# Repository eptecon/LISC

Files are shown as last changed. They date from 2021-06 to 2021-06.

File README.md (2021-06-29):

LISC: Line Image Sensor Controller
======

The Line Image Sensor Controller (LISC) is a universal electronics board that contains readout electronics for various linear image sensors (CCD, CMOS APS, FPA). 
It can be connected to a data acquisition controller (e. g. microcontroller) for further data processing and transmission to a higher-level system. 
The LISC can be used within optical spectrometers and industrial linear cameras.

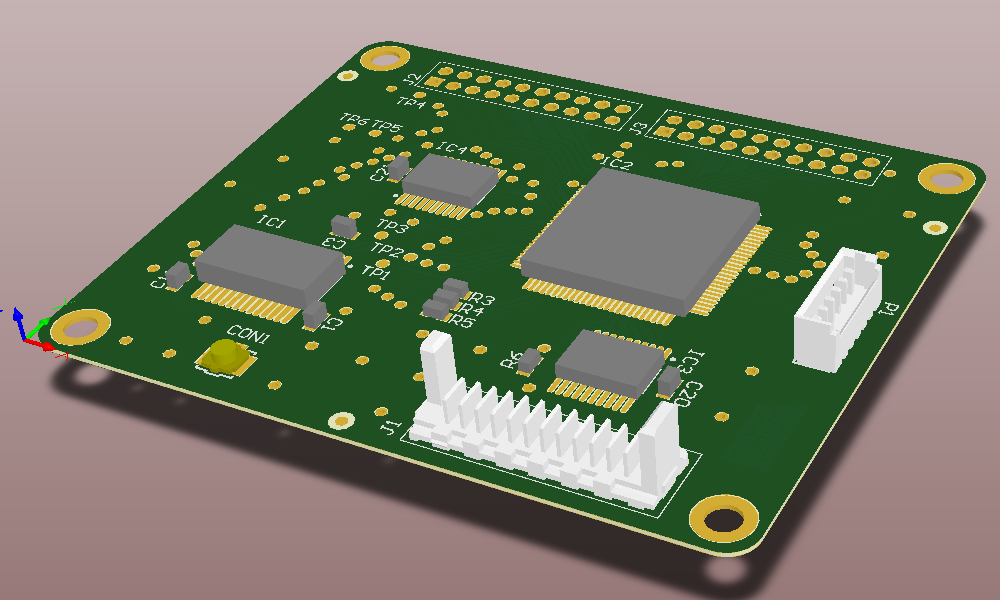
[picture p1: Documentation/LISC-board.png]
 

### Hardware

The Hardware consists of the Electronic Board and the Readout Logic written in VHDL and running on a Xilinx CPLD. See [Documentation](/Documentation/LineImageSensorController.pdf) for details.

### Firmware

The test firmware runs on a STM32F407 microcontroller. It requests the digital video data over DCMI interface using DMA controller and provides it over serial interface
to a user PC.

---

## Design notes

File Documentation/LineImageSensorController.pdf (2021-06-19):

## Line Image Sensor Controller (LISC)

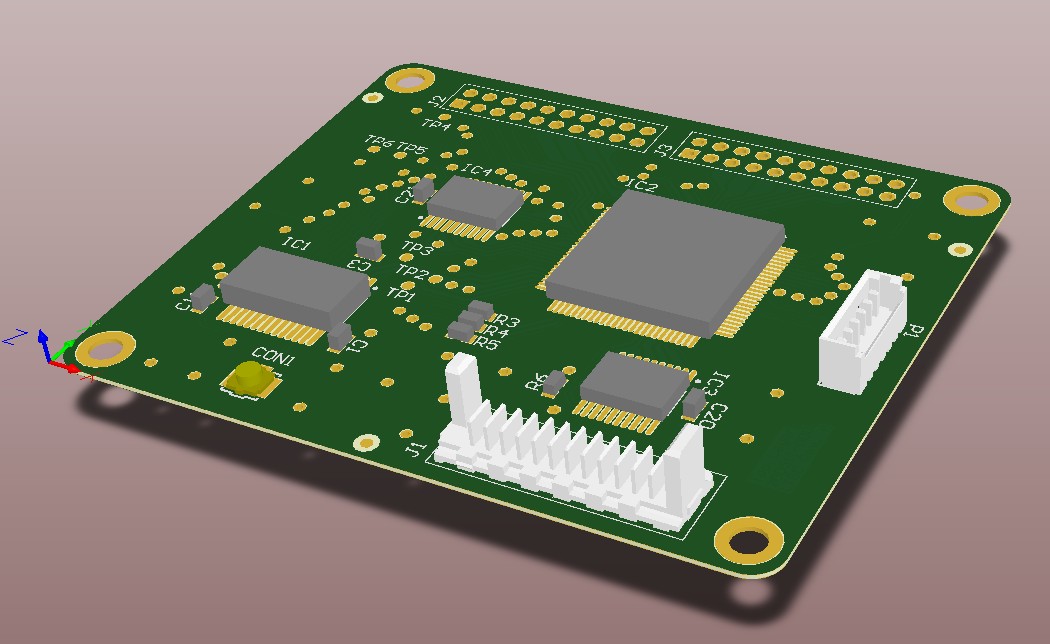
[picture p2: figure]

### 1 Short Description

The Line Image Sensor Controller (LISC) is a universal electronics board that contains readout electronics for various linear image sensors (CCD, CMOS APS, FPA). It can be connected to a data acquisition controller (e. g. microcontroller) for further data processing and transmission. The LISC’s main applications are optical spectrometers and industrial linear camera systems.

The LISC contains following parts:
- Analog-Frontend:
- High resolution: 16 Bit AD-Converter
- Dynamic area: >12 Bit (with adjusted gain)
- Correlated Double Sampling/Sample and Hold circuity
- Programmable gain: 1x to 6x
- Programmable offset. ±300mV
- Fast Readout Logic with Parallel Digital Camera Interface
- Max. readout speed: 2000 kPixels/s
- 4 programmable readout speeds: (500, 1000, 1500 und 2000 kPixel/s)
- Programmable integration time (1,05ms to 60s --> depending on applied line image sensor)
- 8-bit parallel synchronous digital camera interface

### 2 Detailed Specification

### 2.1 Line Image Sensor Controller (LISC)

The Line Image Sensor Controller (LISC) consists of two subsystems: an analog front end and a fast readout logic.
The analog front end contains a video signal processor with analog signal preprocessing and a 16-bit AD converter.
The readout logic is implemented on a CPLD and is used to generate clock signals for various line sensors (tested with CCD line sensors from Sony: ILX511, ILX554). Additionally, the logic takes over the configuration and control of the analog signal preprocessing and the AD conversion. The video data is output via 8-bit parallel (pixel by pixel) synchronous digital camera interface.
The interface to the line image sensor consists of a 12-pin male connector for supply and clock control signals as well a U.FL connector for the analog video signal.

The data interface consists of an 8-bit digital camera interface for video data and a serial interface for configuration of the LISC. The system can be controlled directly via 4 additional inputs. (The data interface can be adapted to use the LISC as a stand-alone module. 8 additional GPIOs are reserved for this purpose.)

LISC Specification
AD-Converter | | | 16Bit
Converion rate | | | 500, 1000, 1500, 2000kSps
Video signal input | 0V bis 4V
Input capacity | | | 10pF
Programmable gain | 0dB bis 16dB (1x bis 6x)
Programmable offset | ±300 mV (tbd (counts))
Elctrical distortion/non-linearity | tbd (counts)
Temperature drift | tbd (counts/°C)
Max. readout speed | 2000kPixel/s
Programmable integration time | 1,05ms to 60ms
Power consumption (w/o sensor) | 1,1W

LISC Line Image Sensor Interface
Pin number | Pin name | I/O | Function
Analog Video Input
CON1-1 | AI1 | IN | Analog video signal
CON1-2 | GND | PWR | analog ground
Line Image Sensor Control Interface
J1-1 | GND | PWR | reserved
J1-2 | SCL | OUT | reserved for I2C
J1-3 | SDA | IN/OUT | reserved for I2C
J1-4 | 3V3 | PWR | reserved
J1-5 | 5V | PWR | supply line sensor
J1-6 | GND | PWR | supply line sensor
J1-7 | RESET1 | OUT | ROG/START – readout start
J1-8 | SENCLK1 | OUT | CLK – readout clock
J1-9 | ADCTRIG | IN | reserved
J1-10 | SENCLK3 | OUT | reserved
J1-11 | RESET2 | OUT | reserved
J1-12 | SENCLK2 | OUT | reserved

LISC Data and
Configuration Interface
Pin number | Pin name | I/O | Function
Serial Config Interface
J2-2 | SCLK | IN | serial clock
J2-4 | MOSI | IN/OUT | serial data
J2-6 | MISO | IN/OUT | serial data
J2-8 | CS | IN | chip select
Parallel Digital Camera Interface
J2-13 | PIXCLK | OUT | pixel clock
J2-15 | VSYNC | OUT | vertical synchronisation
J2-17 | HSYNC | OUT | horizontal synchronisation
J3-4 | DA[0] | OUT | data bit 0
J3-6 | DA[1] | OUT | data bit 1
J3-8 | DA[2] | OUT | data bit 2
J3-10 | DA[3] | OUT | data bit 3
J3-12 | DA[4] | OUT | data bit 4
J3-14 | DA[5] | OUT | data bit 5
J3-16 | DA[6] | OUT | data bit 6
J3-18 | DA[7] | OUT | data bit 7

### 4 Control-I/Os

Pin number | Pin name | I/O | Function
J2-12 | RESET | IN | digital camera reset
J2-14 | START | IN | exteral trigger/start readout
J2-16 | EXTCLK | IN | digital camera main clock
J2-18 | READY | OUT | readout ready
J2-20 | RST | IN | system reset
8x DATA I/Os reserved for alternative interface
Pin number | Pin name | I/O | Function
J3-3 | DB[0] | IN/OUT | reserved
J3-5 | DB[1] | IN/OUT | reserved
J3-7 | DB[2] | IN/OUT | reserved
J3-9 | DB[3] | IN/OUT | reserved
J3-11 | DB[4] | IN/OUT | reserved
J3-13 | DB[5] | IN/OUT | reserved
J3-15 | DB[6] | IN/OUT | reserved
J3-17 | DB[7] | IN/OUT | reserved

### 2.2 Power Supply (PWS)

The Line Image Sensor Controller (LISC) requires stable filtered power supply of 5V from a higher-level system. It has a linear converter on board to create 3.3V for local supply and feeds 5V through to supply line image sensor.

PWS Specification
Voltage input | 5V
Voltage output | 5V
Power consumption max. | >2.5W (tbd)

PWS
Connector
P3
Pin number | Pin name | I/O | Function
J2-1 | 5V | PWR | 5V Supply
J2-2 | GND | PWR | ground

### 2.3 General

The Line Image Sensor Controller (LISC) is implemented on a Printed Circuit Board with the size of 60mmx50mm. The maximum height of populated board is equal or smaller than 12mm.
Storage temperature: -65°C to 150°C
Operating temperature: 0°C to 70°C

### 3 System Description Readout Logic

The readout logic is the main component of the LISC. It is implemented as VHDL code on a CPLD so that the electronic card can be used with different line sensors (CCD, CMOS APS or FPA) by making minor adjustments to the firmware. (the function was tested with ILX511 / ILX554 of CCD line sensors from Sony.)
The readout logic configures and controls the analog signal preprocessing and digitization of sensor data. It also controls the reading of the line sensor and the transmission of the data to a microcontroller.
The readout logic can be controlled directly via three lines. Various parameters (such as readout speed, integration time, etc.) can be set on a register basis via a serial interface. The readout logic consists of several VHDL modules that implement various functions. The individual modules are briefly described below.

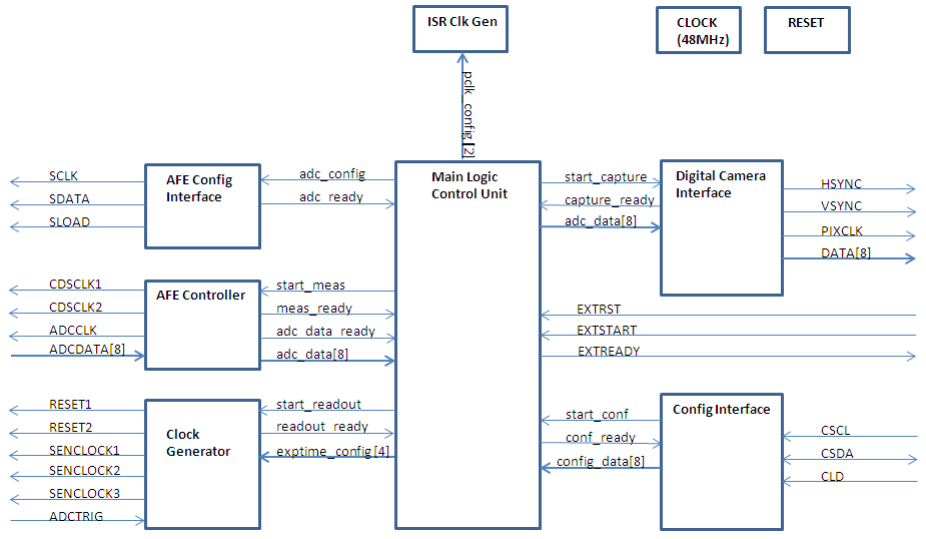
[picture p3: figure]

### 3.1 AFE Config Interface

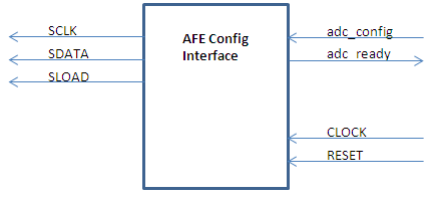
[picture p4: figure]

The AFE-Config Interface (Analog Front-End Config Interface) module configures the AD-converter at every start / reset, or if configuration parameters have been changed via the serial interface of the AD-converter. 8 registers are written to in the AD-converter.

Configuration data of the AD-Converter (AD9826):
- Signal input range (4V or 2V)
- Internal reference (on/off)
- 3-channel-/2- channel -/1- channel -mode (adjustable)
- Analog readout configuration (“correlated double sampling” or “sample and hold“)
- Input clamp bias (4V/3V)
- Sleep mode (on/off)
- Output mode (16Bit/8Bit)
- Multiplexer config (RBG/BGR)
- Channel selection (R/G/B)
- PGA gain (1 bis 6)
- Offset (-300mV bis +300mV)

### 3.2 AFE Controller

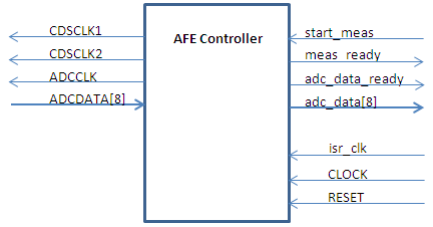
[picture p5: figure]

This module generates signals for sampling (CDS or SHA) and for digitizing the video signal. The signals are then applied to the outputs at the specified times via two control lines. Every time a data item is present at the AD converter output, the adc_data_ready signal is set. The module works synchronously with isr_clk.

### 3.3 Clock Generator

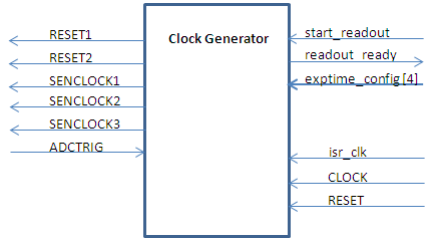
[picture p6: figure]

The clock generator module runs synchronously with isr_clk and generates clock and reset signals for the readout of the line sensor. A different clock generator can be used depending on the line sensor type. The integration time is selected via a 4-bit line.

### 3.4 Main Logic Control Unit

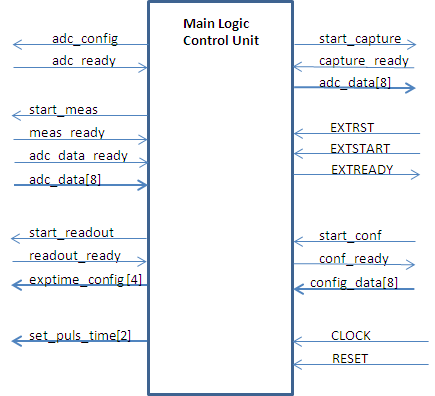
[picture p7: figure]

This module controls all processes (reading, sampling, digitizing, transferring) of the entire readout logic, configures the AD converter, and sets the readout and integration time according to the specified values.
The module is based on a state machine with 3 states:
1. Init: State after switching on / resetting. The system starts the configuration of the AD converter with the existing configuration data. After the successful configuration, the system changes to the second state.
2. Wait for Measurement: The readout process is started in this state. The reading of the line sensor takes place periodically until an external measurement is triggered. The system then changes to the "Measurement" state.
3. Measurement: After triggering, a measurement is carried out. After the configured integration time the digitized data is transmitted to the digital camera output. The system then returns to state 2. If a continuous measurement has been set via the config register, the system remains in that state and continuously sends measurement data to the host. The continuous measurement can only be stopped by an external reset signal.

In the fourth state „CONFIG“ (not implemented yet) the global configuration data (e.g. integration time) are read in and all registers of the readout logic are loaded accordingly.

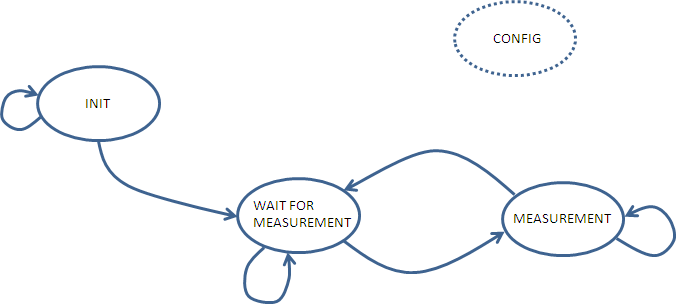
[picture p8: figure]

Higher Level configuration data for Readout Logic von Auslese-Logik:
- Integration time (1,05ms bis 60s)
- Readout speed (0,5MHz bis 2MHz)
- Measurement mode (Einzelmessung/Dauermessung)
- Analog frontend configuration (gain, offset, output mode (8Bit/16Bit))

### 3.5 Digital Camera Interface

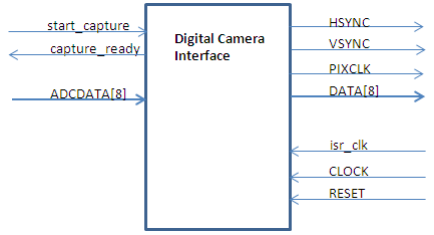
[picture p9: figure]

This module serves as an interface to the host system (e.g. to a microcontroller). It is based on a parallel synchronous digital camera interface with 8-bit data width. For the test system an STM32F407 microcontroller was used. This microcontroller can receive the data via its DCMI interface using Direct Memory Access (DMA) and store or process it further.

### 3.6 Config Interface

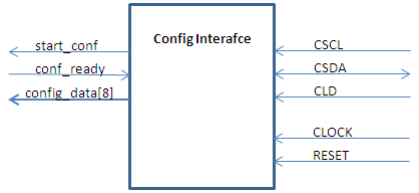
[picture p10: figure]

This module contains a serial interface for higher level configuration of the readout logic. The configuration interface module has not been implemented yet since it requires a more precise specification first.

### 3.7 ISR-Clock Generator

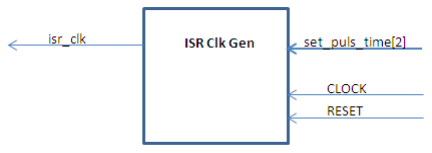
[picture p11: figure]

The ISR clock generator module generates the isr_clk signal from the 48Mhz oscillator, which is used as the main clock for the AFE controller and clock generator as well as for the digital camera interface. The input set_puls_time is used to select the readout speed that was configured on startup.

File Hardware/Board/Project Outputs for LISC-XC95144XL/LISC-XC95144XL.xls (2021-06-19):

Board Stack Report
Stack Up |  |  |  |  | Layer Stack
Layer | Board Layer Stack | Board Layer Stack | Board Layer Stack | Board Layer Stack | Name | Material | Thickness | Constant
1 |  |  |  |  | Top Paste
2 |  |  |  |  | Top Overlay
3 |  |  |  |  | Top Solder | Solder Resist | 0,010mm | 3,5
4 |  |  |  |  | Top Layer | Copper | 0,036mm
5 |  |  |  |  | Dielectric1 | FR-4 | 0,320mm | 4,8
6 |  |  |  |  | Bottom Layer | Copper | 0,036mm
7 |  |  |  |  | Bottom Solder | Solder Resist | 0,010mm | 3,5
8 |  |  |  |  | Bottom Overlay
9 |  |  |  |  | Bottom Paste
 | Height : 0,411mm | Height : 0,411mm | Height : 0,411mm | Height : 0,411mm

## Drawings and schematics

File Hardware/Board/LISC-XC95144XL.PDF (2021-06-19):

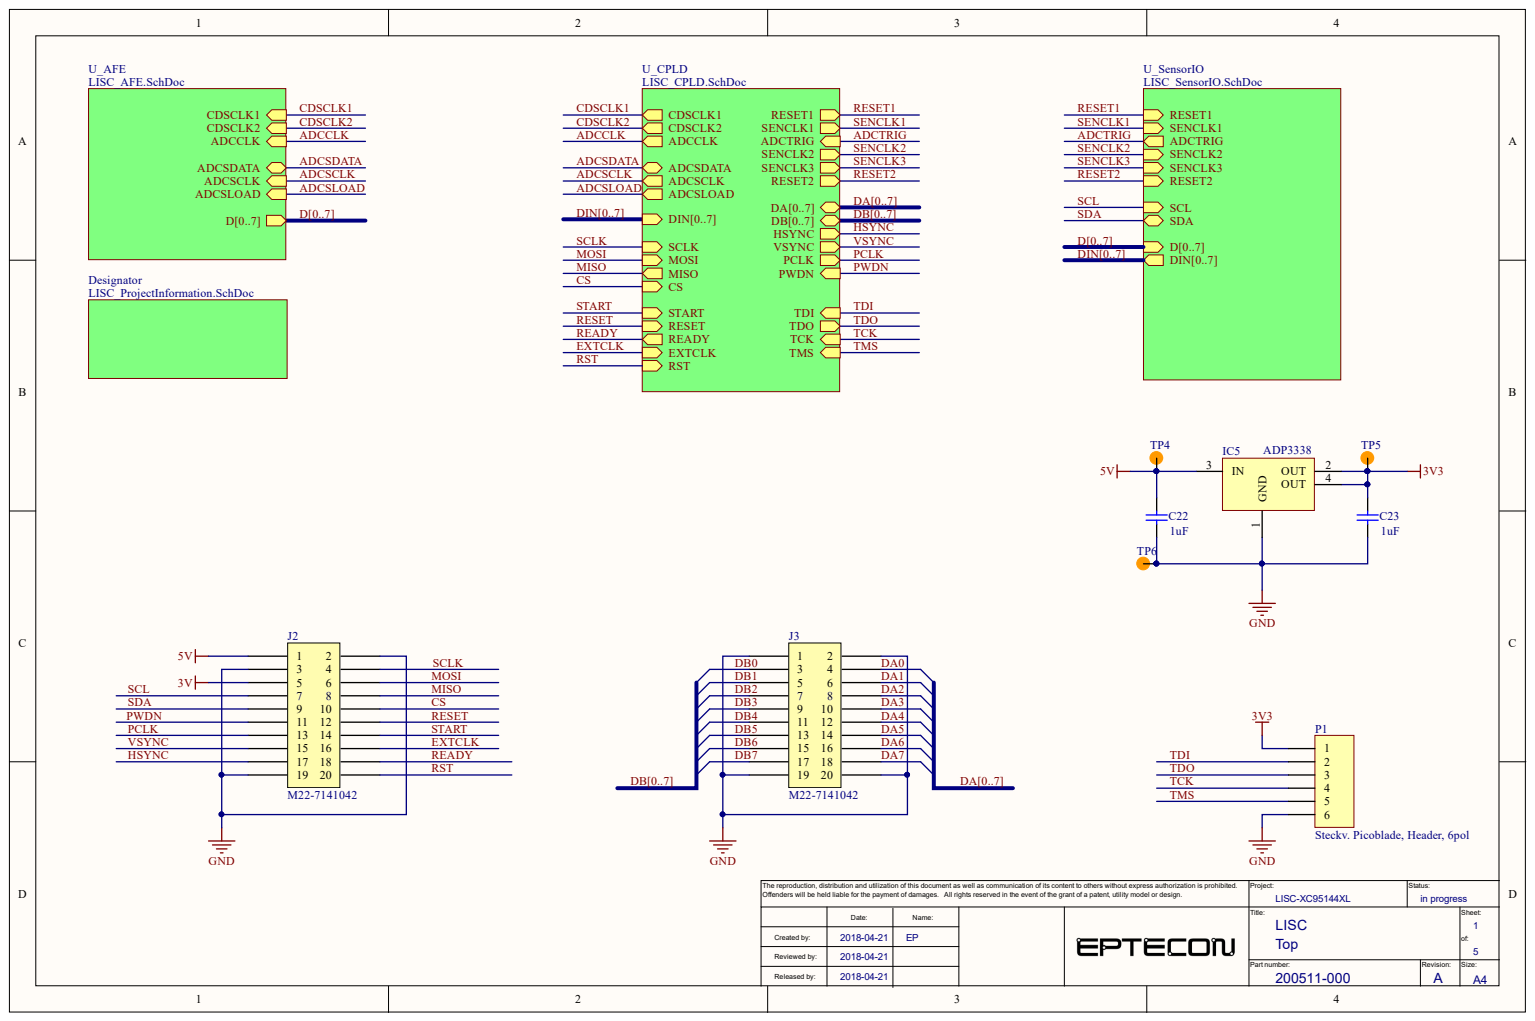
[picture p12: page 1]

The reproduction, distribution and utilization of this document as well as communication of its content to others without express authorization is prohibited. Offenders will be held liable for the payment of damages. All rights reserved in the event of the grant of a patent, utility model or design. | Project: LISC-XC95144XL | Status: in progress

Date: | Name: | Title: LISC Top | Sheet: 1 of: 5

Created by: | 2018-04-21 | EP

Reviewed by: | 2018-04-21

Part number: 200511-000 | Revision: A | Size: A4

Released by: | 2018-04-21

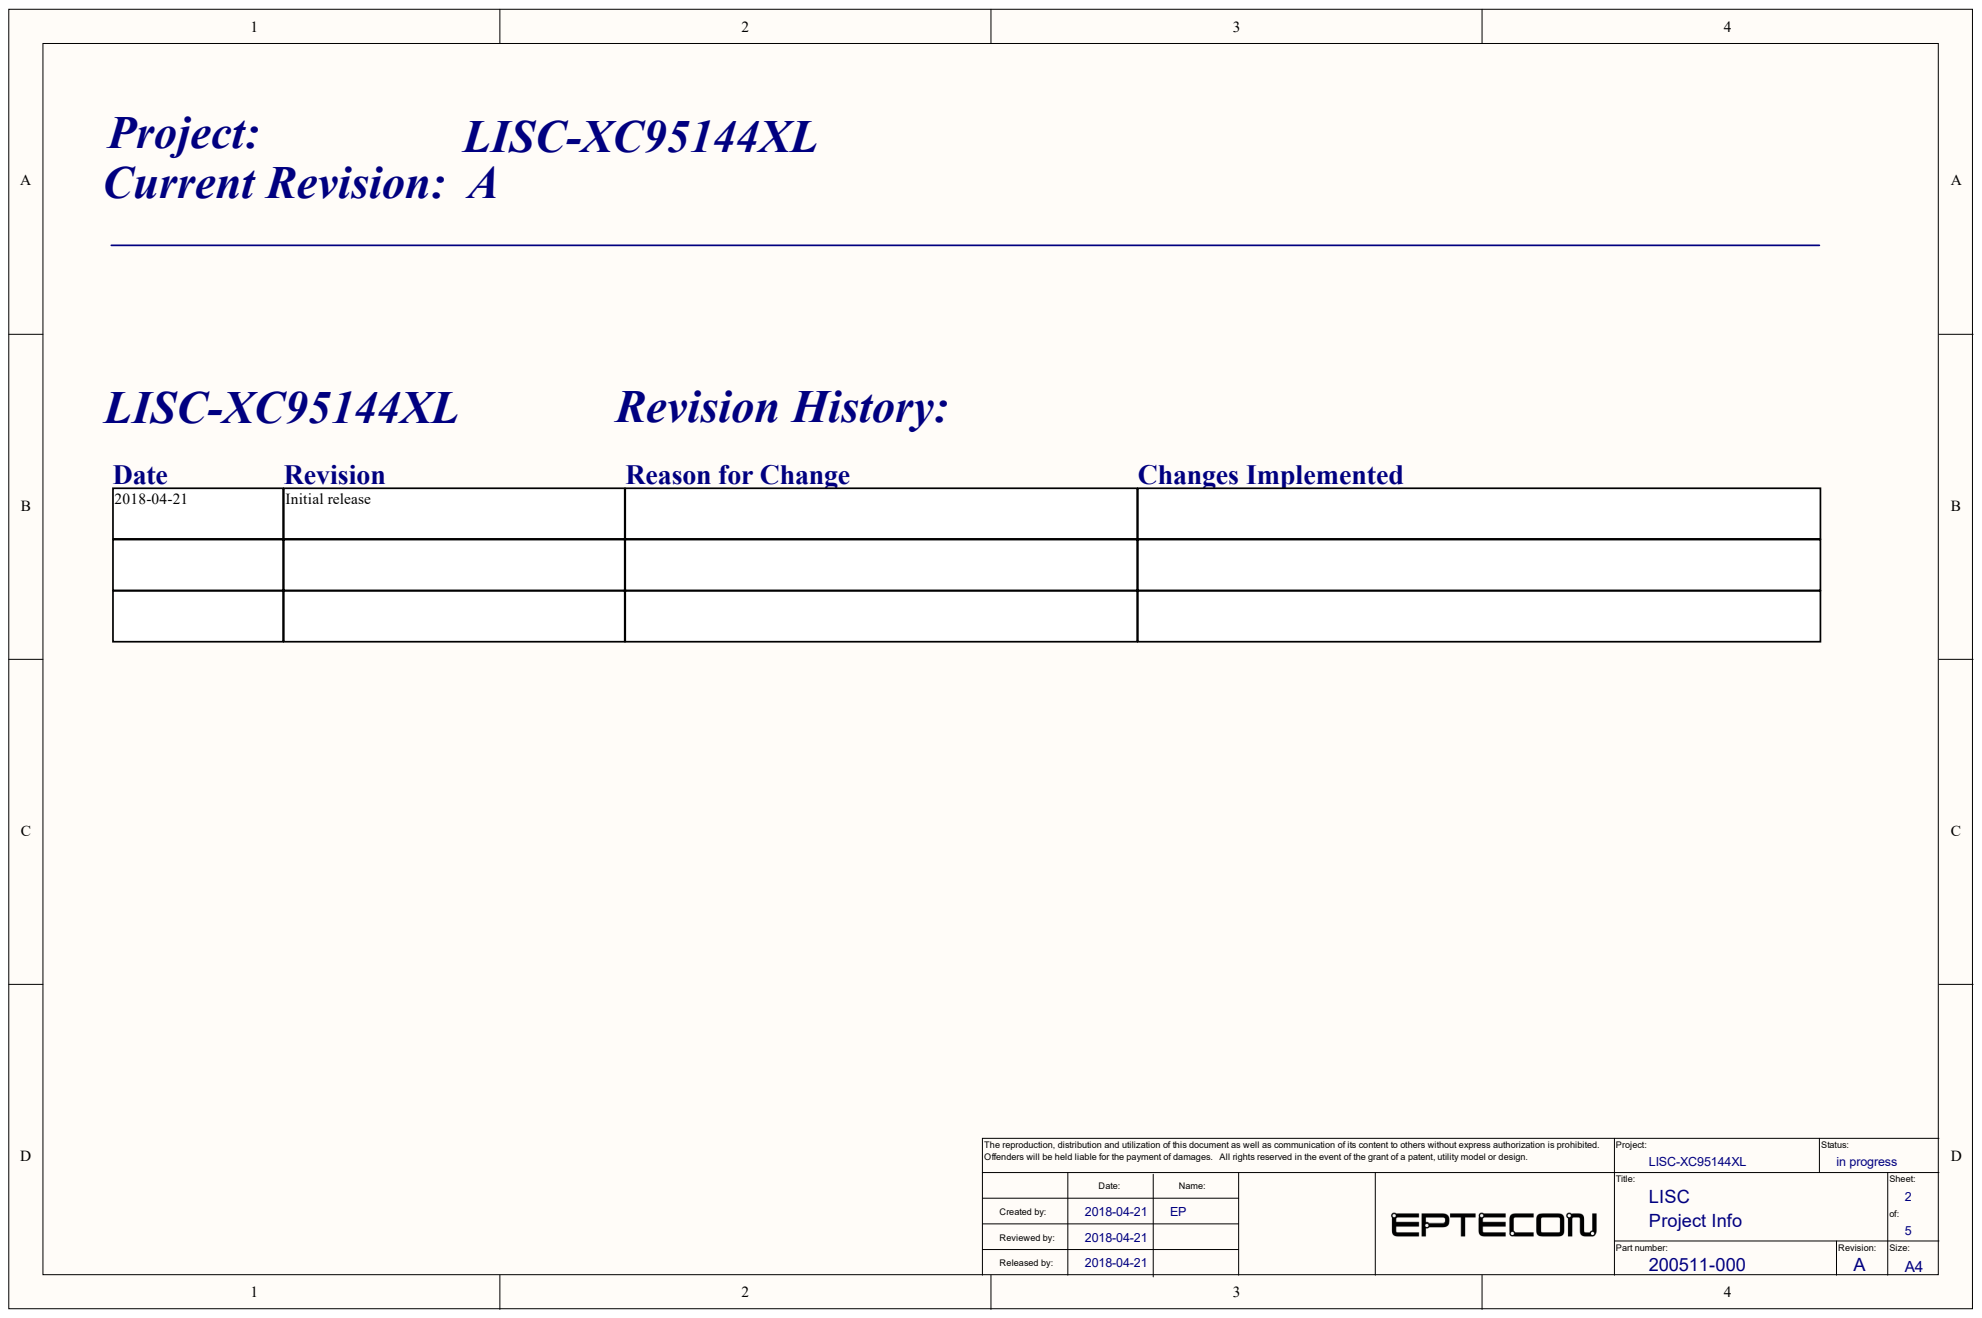
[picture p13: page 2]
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

Date: | Name: | Title: LISC Project Info | Sheet: 2 of: 5

Created by: | 2018-04-21 | EP

Reviewed by: | 2018-04-21

Part number: 200511-000 | Revision: A | Size:

Released by: | 2018-04-21

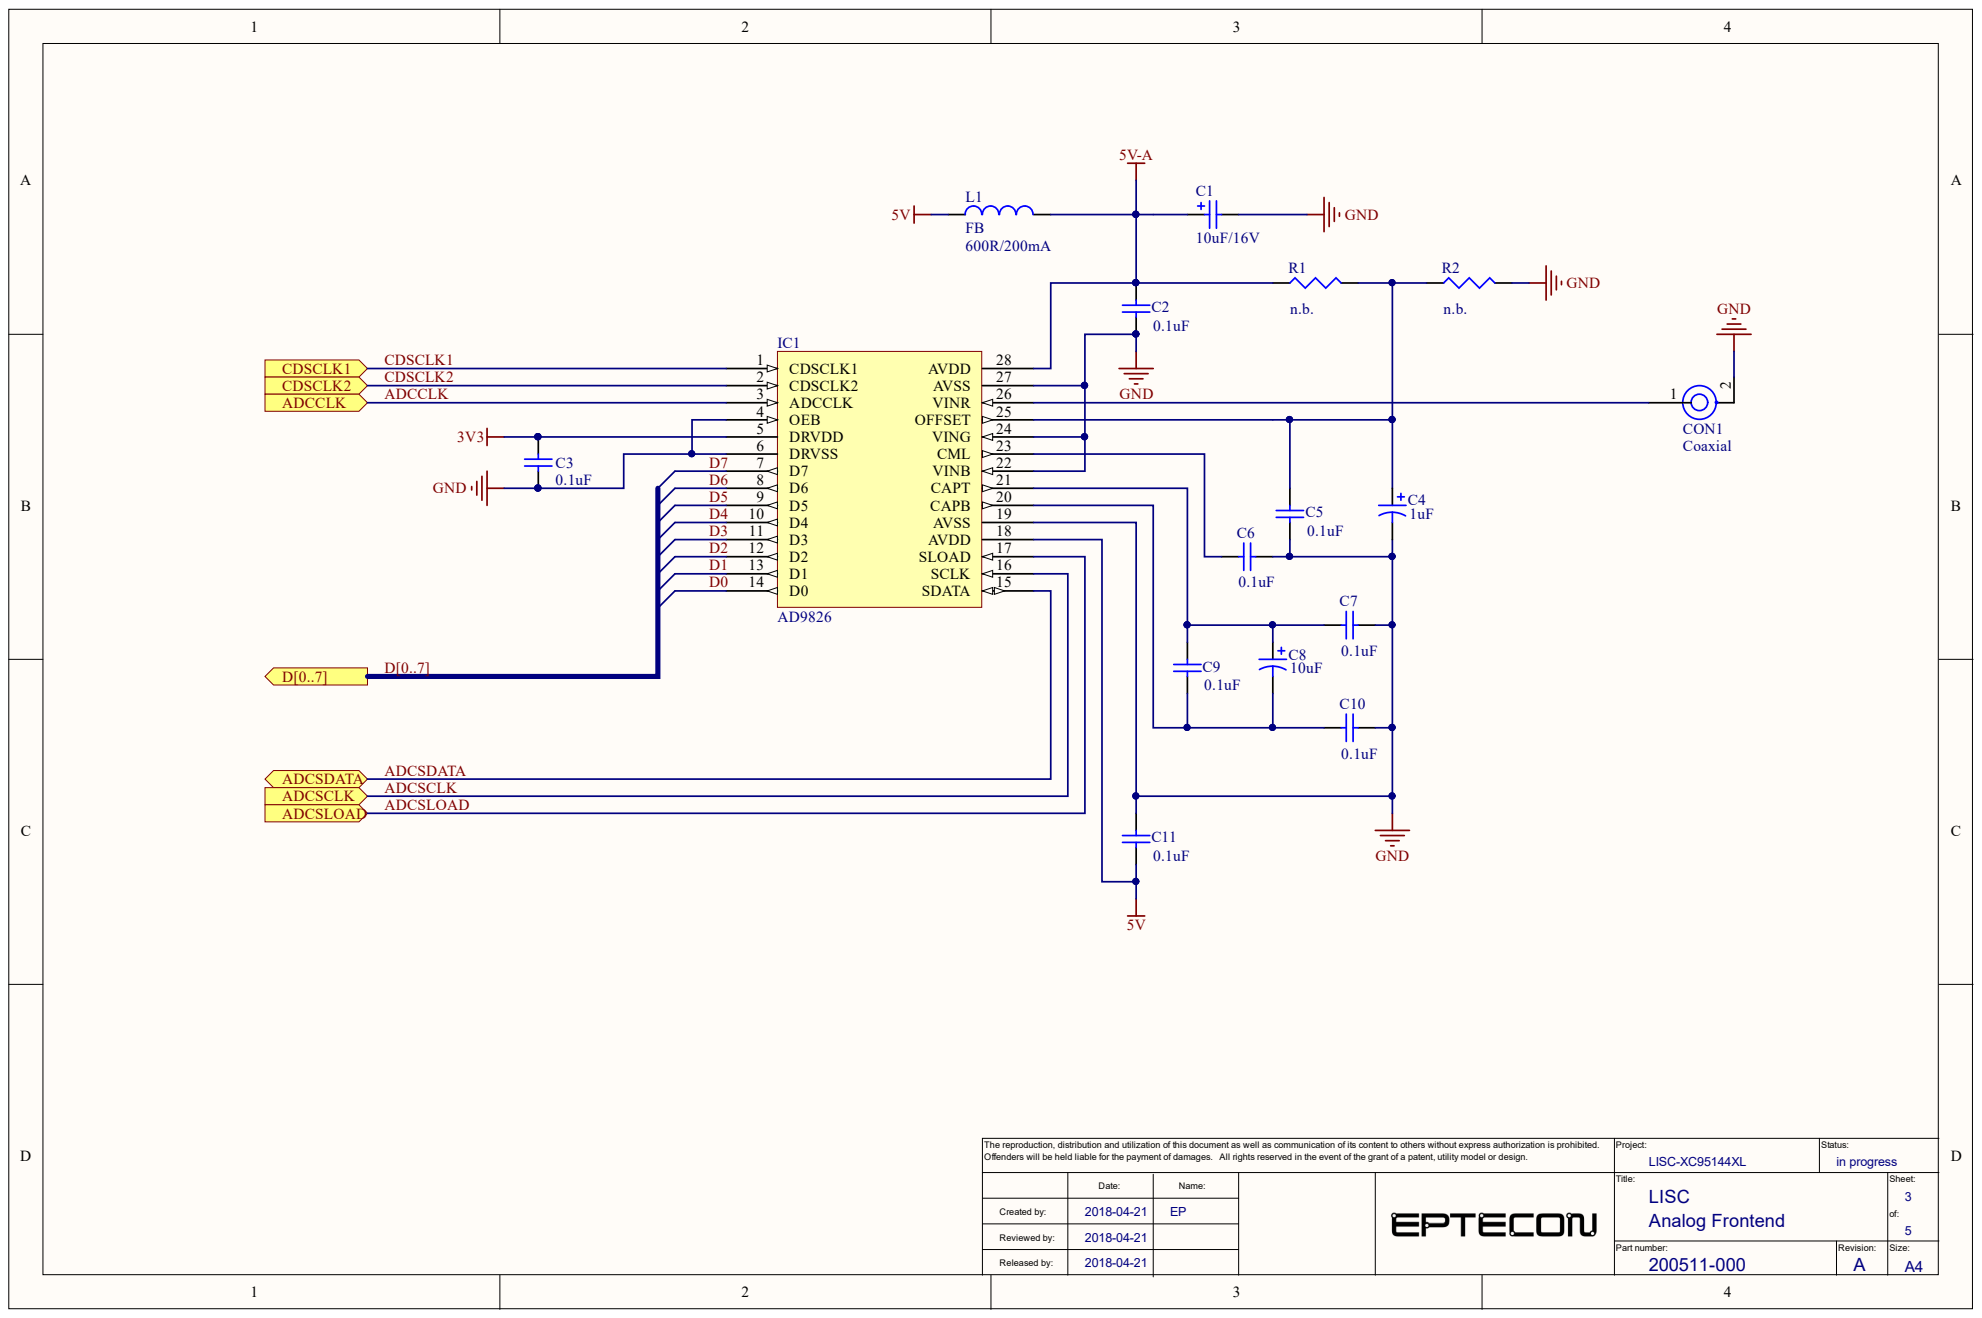
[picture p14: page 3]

5 | | 16 SLOAD 17 AVDD 18 AVSS 19 CAPB 20 CAPT 21 VINB 22 CML 23 VING 24 OFFSET 25 VINR 26 AVSS 27 AVDD 28 5 SCLK

D 1 1 3 | D 1 | | u F
D 0 1 | | 1

D[0..7 ] | | D 0 ATA

The reproduct ion, dist r ibut ion and ut i l izat ion of this document as wel l as com municat ion of i ts content to others w i thout express author izat ion is prohibi ted. O ffenders w i l l be held l iable for the payment of damages. A l l r ights reserved in the event of the grant of a patent , ut i l i ty model or design. | P roject : LISC-XC9 5 1 4 4 X L | S tatus: in p r o g r ess

Date: | Name: | T i t le: LIS C Analog F rontend | Sheet : 35 of :

C reated by: | 2 0 1 8 -0 4 -2 1 | E P

Reviewed by: Released by: | 2 0 1 8 -0 4 -2 1

Part number : 200511-000 | Revision: A | S ize:

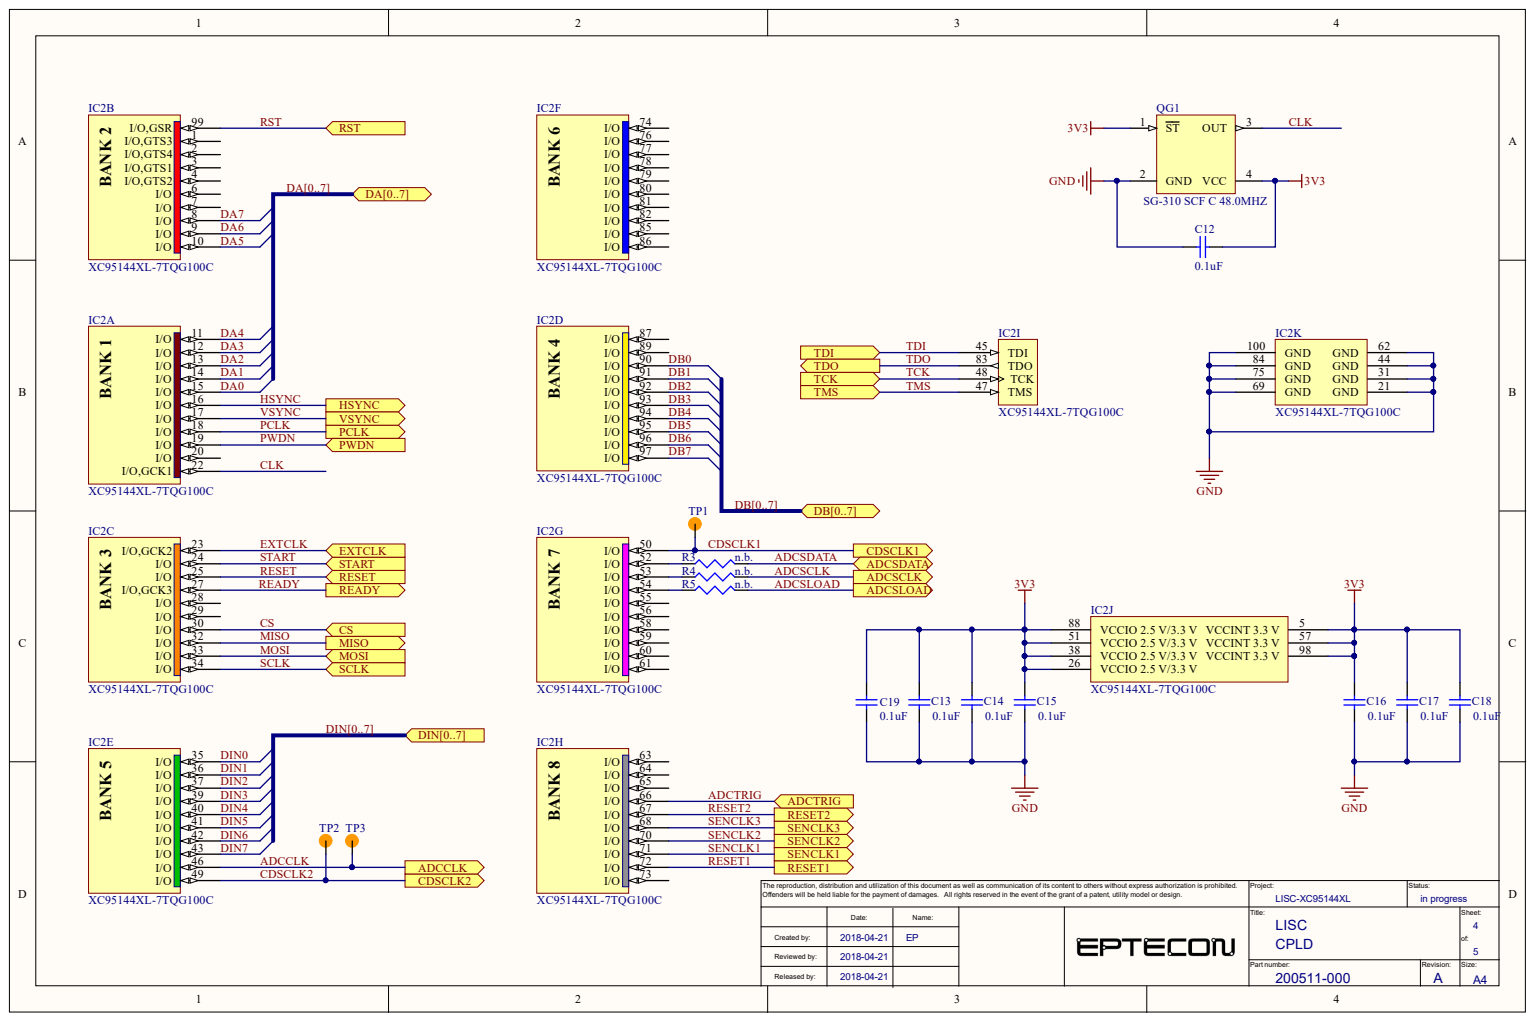
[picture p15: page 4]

8 4 | 4 4
7 5 | 3 1

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

Date: | Name: | T i t le: LIS C CPLD | Sheet : 45 of :

C reated by: | 2 0 1 8 -0 4 -2 1 | E P

Reviewed by: Released by: | 2 0 1 8 -0 4 -2 1

Part number : 200511-000 | Revision: A | S ize:

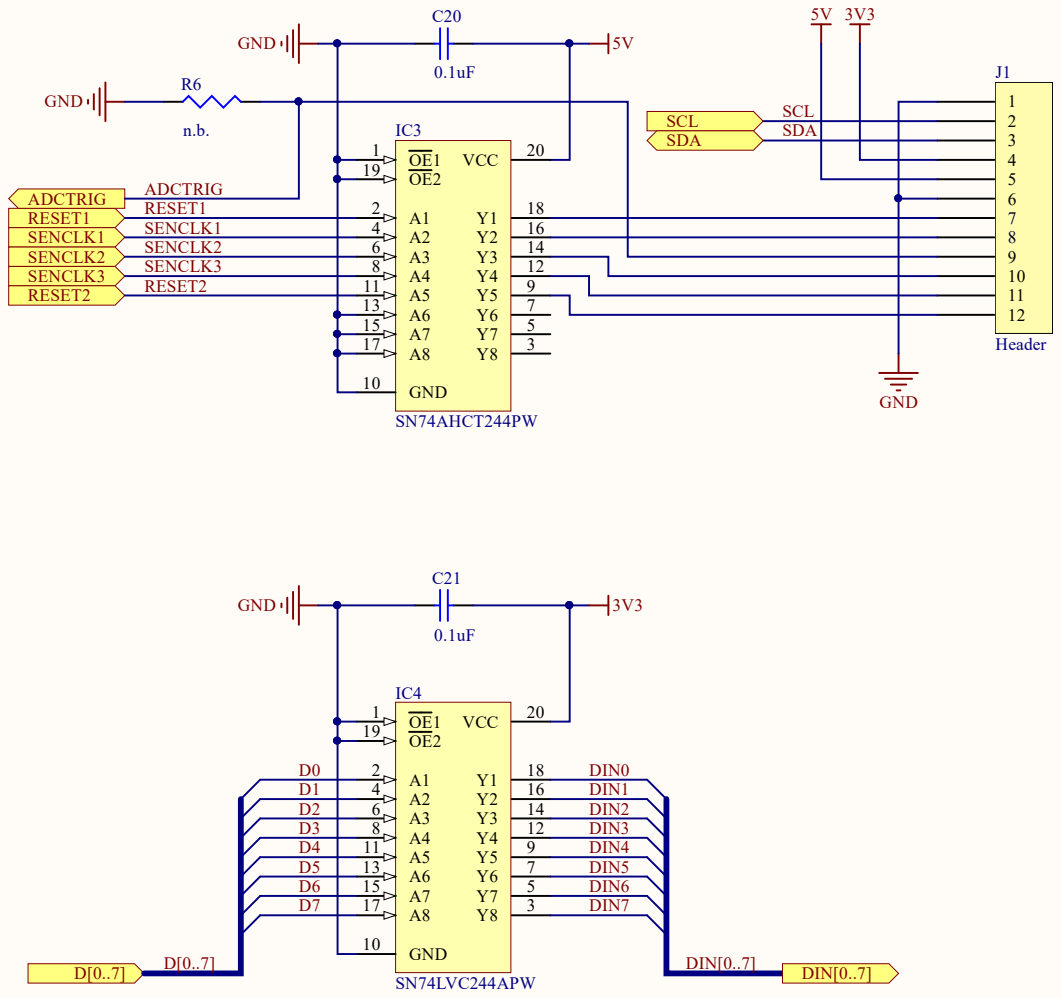
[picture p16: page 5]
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

Date: | Name: | Title: LISC Sensor I/O | Sheet: 5 of: 5

Created by: | 2018-04-21 | EP

Reviewed by: | 2018-04-21

Part number: 200511-000 | Revision: A | Size:

Released by: | 2018-04-21

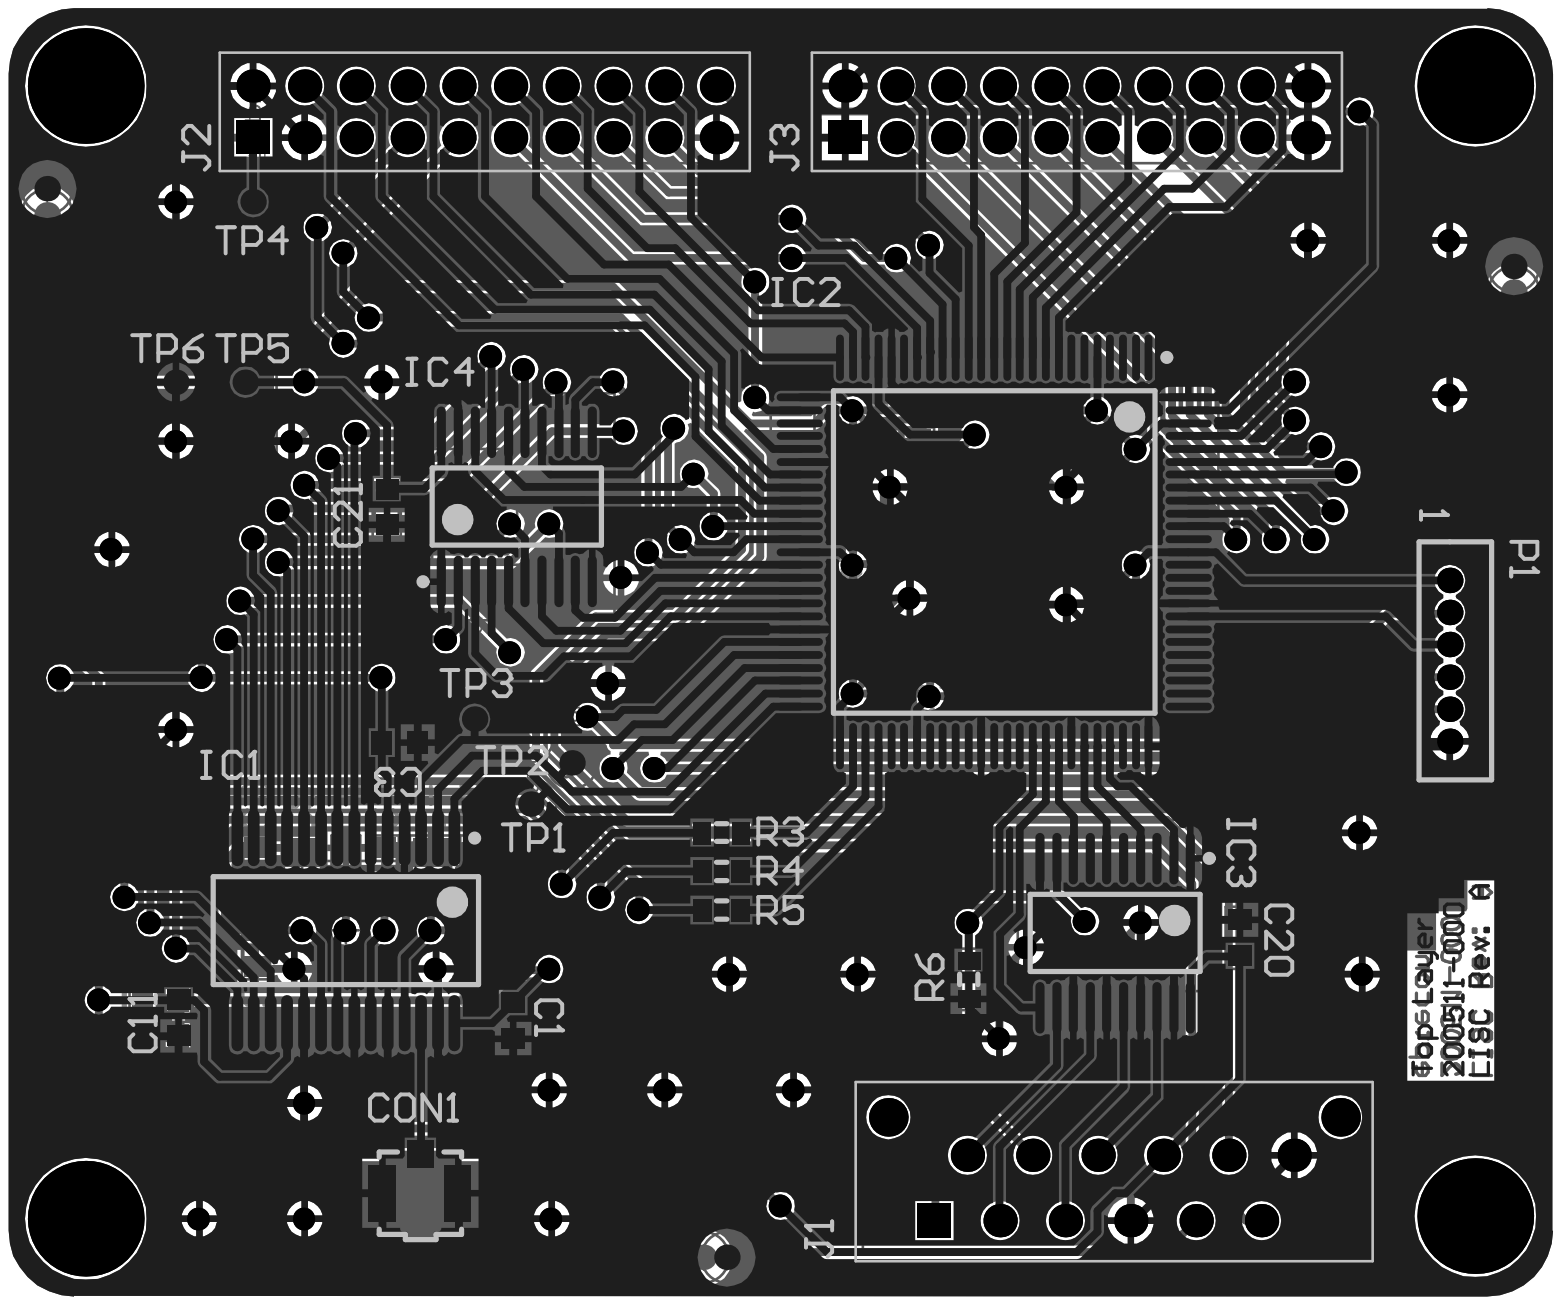
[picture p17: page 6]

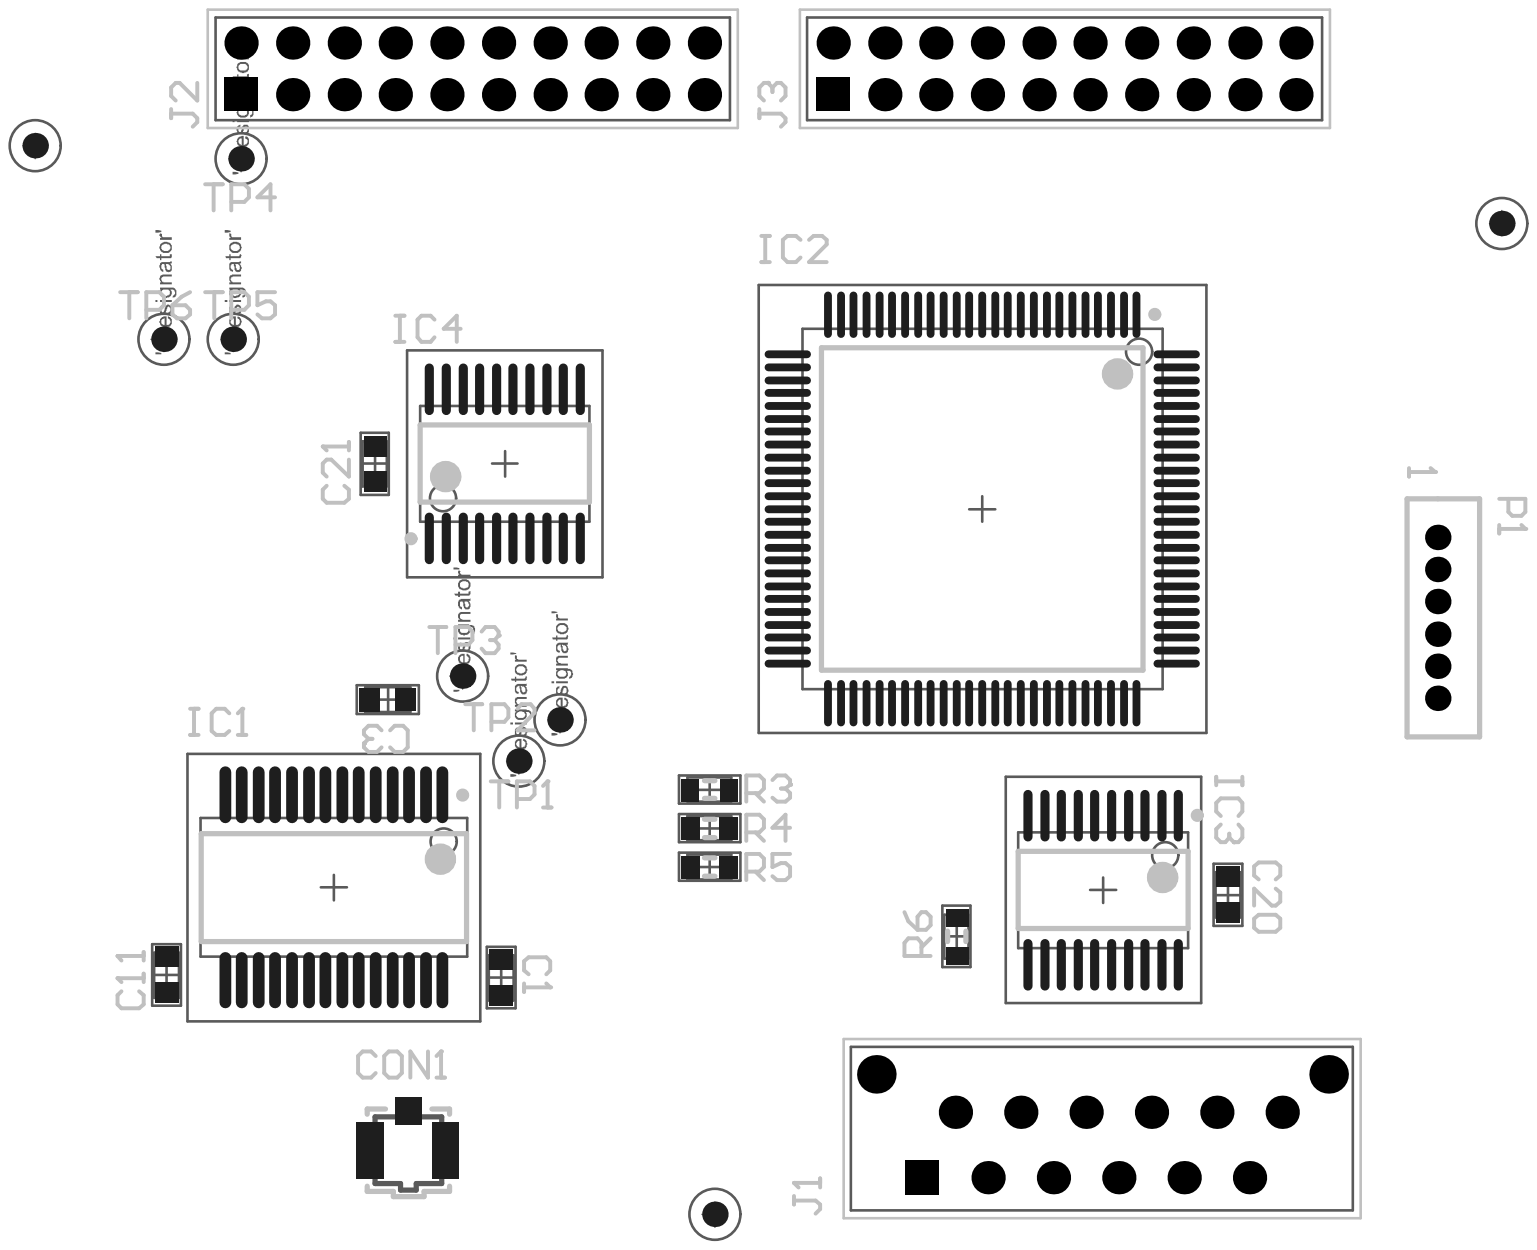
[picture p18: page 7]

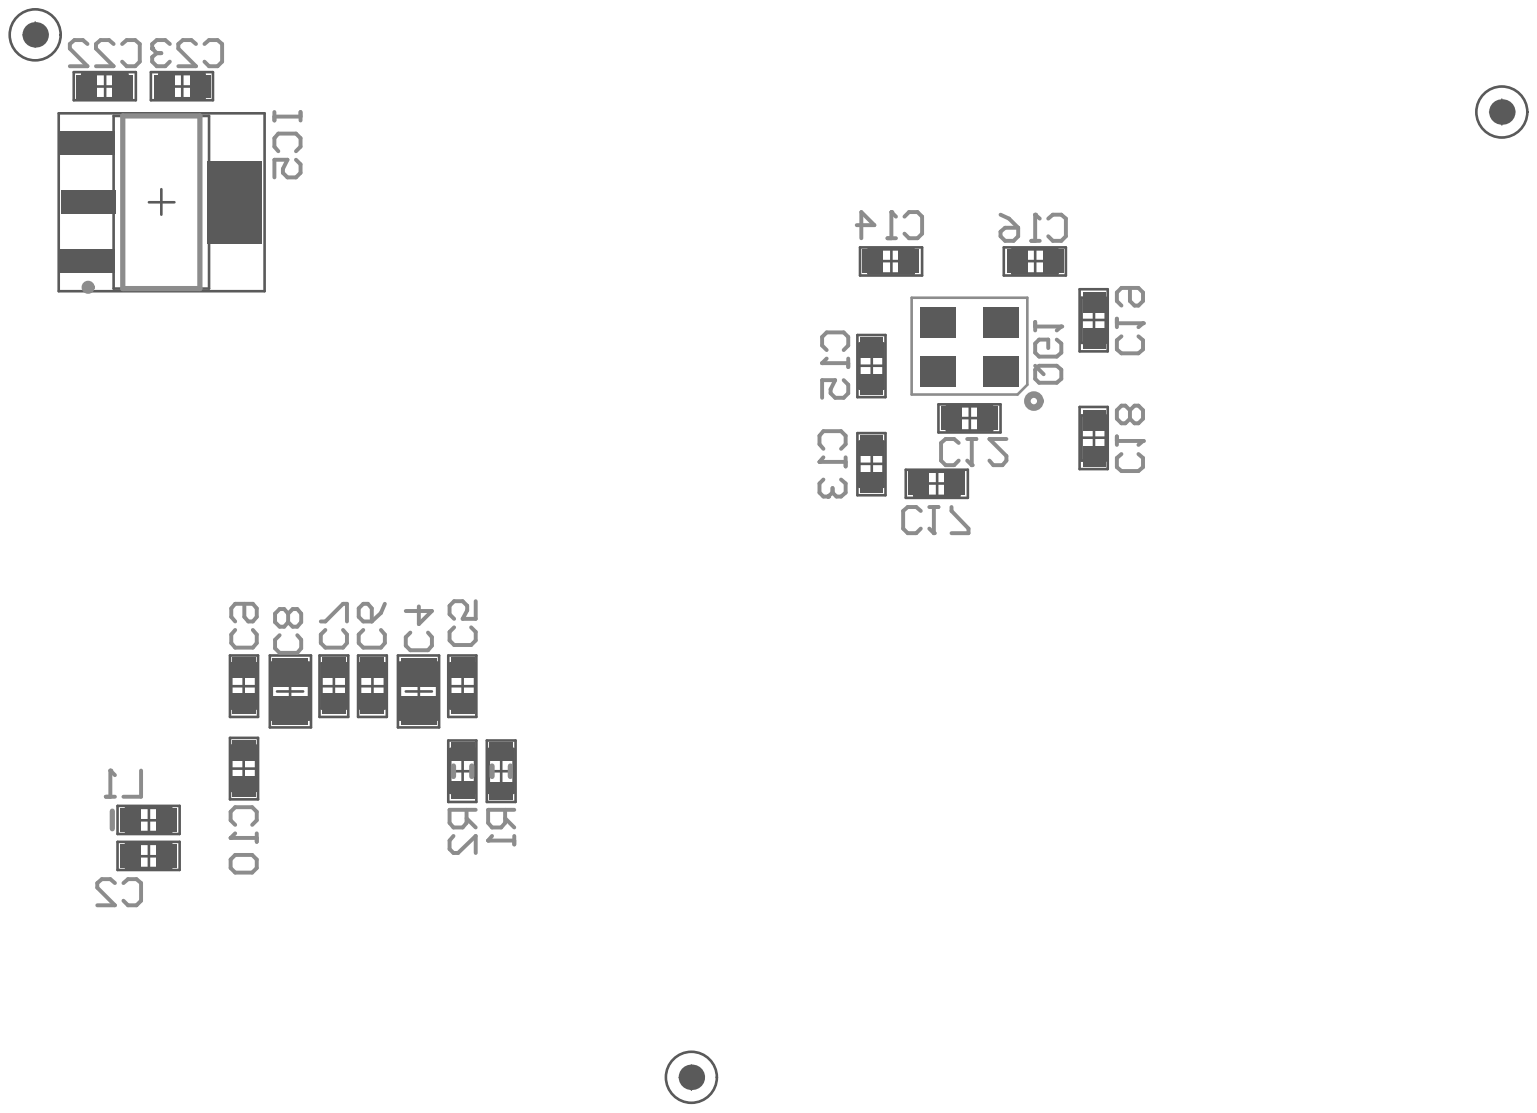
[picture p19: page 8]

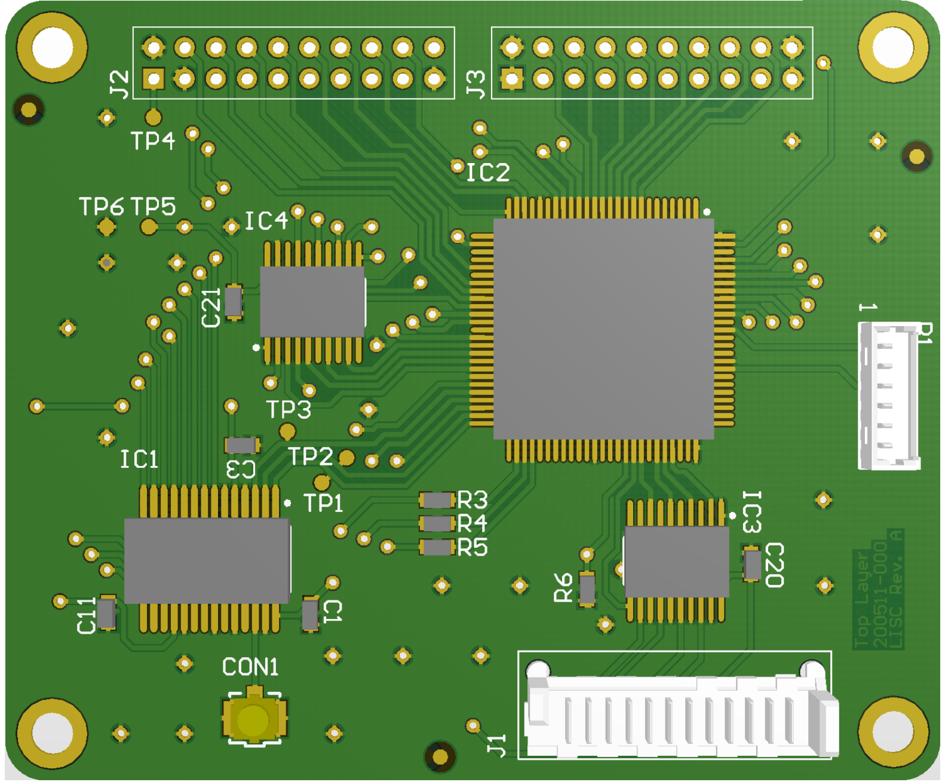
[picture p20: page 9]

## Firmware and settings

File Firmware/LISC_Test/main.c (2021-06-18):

/**
  ******************************************************************************
  * @file    main.c
  * @author  EP
  * @version V1.0.1
  * @date    04-November-2018
  * @brief   Main program body
  ******************************************************************************
  */

/* Includes ------------------------------------------------------------------*/
#include "stm32f4xx.h"
#include "system.h"
#include "stm32f4xx_dcmi.h"
#include "stm32f4xx_dma.h"

/* macro -------------------------------------------------------------*/
#define TxBufferSize1   (countof(TxBuffer1) - 1)
#define TxBufferSize2   (countof(TxBuffer2) - 1)

#define countof(a)   (sizeof(a) / sizeof(*(a)))

/* variables ---------------------------------------------------------*/
uint8_t TxBuffer1[] = "The quick brown fox jumps over the lazy dog\r\n";
uint8_t TxBuffer2[] = "2 USART DMA Polling: USARTz -> USARTy using DMA";
uint8_t RxBuffer1[2049];
uint8_t RxBuffer2[TxBufferSize1];

/* flags */
uint8_t Start = 1;
uint8_t DataReady = 0;
uint8_t CaptureData = 0;

/* function prototypes -----------------------------------------------*/
void MainFunction(void);


void main(void)
{
    /* System Initialisation */
	SysInit();
    
	while (1)
        {
            MainFunction();
		}

}/* main */


void MainFunction(void)
{

	/* MainFunction */
	if ((GPIO_ReadInputDataBit(GPIOA, GPIO_Pin_0) == 1))
	{
		GPIO_SetBits(GPIOA, GPIO_Pin_5);
		GPIO_SetBits(GPIOD,  GPIO_Pin_13);
		DMA_ClearITPendingBit(DMA1_Stream6, DMA_IT_TCIF6);
		DMA_ClearITPendingBit(DMA2_Stream1, DMA_IT_TCIF1);
		DCMI_ClearITPendingBit(DCMI_IT_FRAME);

		//DMA_Cmd(DMA2_Stream1, DISABLE);
		CaptureData = 1;
		Start = 0;

	}

	if(u16CaptureData == 1)
	{
		//Start = 0;
		GPIO_ResetBits(GPIOA, GPIO_Pin_5);
		//GPIO_SetBits(GPIOD,  GPIO_Pin_13);

		DMA_Cmd(DMA2_Stream1, ENABLE);

		DCMI_Cmd(ENABLE);
		Delay(200);

		DCMI_CaptureCmd(ENABLE);

		Delay(200);

		if (DCMI_GetITStatus(DCMI_IT_FRAME))
		  {
		      /* Clear ... interrupt pending bit */
			  DCMI_ClearITPendingBit(DCMI_IT_FRAME);
			  u16DataReady = 1;
			  u16CaptureData = 0;
			  GPIO_SetBits(GPIOD,  GPIO_Pin_15);
		  }

		DataReady = 1;
		//CaptureData = 0;
	}

	if (DataReady == 1)
	{
		Delay(200);

		//DCMI_CaptureCmd(DISABLE);
		//while (i  < sizeof(Data)-1)
		//{
			//while(USART_GetFlagStatus(USART2, USART_FLAG_TC) == RESET);
			//USART_SendData(USART2, Data[i]);
			//i++;
		//}

		//Delay(200);

		if(DMA_GetITStatus(DMA1_Stream6, DMA_IT_TCIF6) == SET)
		{
			//GPIO_SetBits(GPIOD,  GPIO_Pin_12);
			DataReady = 0;
		}

		DMA_Cmd(DMA1_Stream6, ENABLE);
		Delay(2000);

		DataReady = 0;
		//DMA_Cmd(DMA1_Stream6, DISABLE);
		DMA_Stream_IRQHandler();

	}

}/* Main Function */

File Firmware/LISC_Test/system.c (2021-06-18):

#include "stm32f4xx_rcc.h"
#include "stm32f4xx_gpio.h"
#include "stm32f4xx_dcmi.h"
#include "stm32f4xx_dma.h"
#include "stm32f4xx_usart.h"
#include "misc.h"

/* System Clocks Configurations ---------------------------------------------------------*/
void RCC_Config(void)
{
  /* GPIOA, GPIOB, GPIOC and GPIOD Periph clock enable */
  RCC_AHB1PeriphClockCmd(RCC_AHB1Periph_GPIOA | RCC_AHB1Periph_GPIOB | RCC_AHB1Periph_GPIOC | RCC_AHB1Periph_GPIOD, ENABLE);

  /* USART2 Periph clock enable */
  RCC_APB1PeriphClockCmd(RCC_APB1Periph_USART2, ENABLE);

  /* DMA1 clock enable */
  RCC_AHB1PeriphClockCmd(RCC_AHB1Periph_DMA1, ENABLE);

  /* Enable DMA2 clock */
  RCC_AHB1PeriphClockCmd(RCC_AHB1Periph_DMA2, ENABLE);

  /* DCMI clock enable */
  RCC_AHB2PeriphClockCmd(RCC_AHB2Periph_DCMI, ENABLE);
}/* RCC_Config */


/* GPIO Configurations ---------------------------------------------------------*/
void GPIO_Config(void)
{
  GPIO_InitTypeDef  GPIO_InitStructure;


  /* USART GPIO Configurations ---------------------------------------------------------*/
  /* Configure PA2 for USART2 TX as AF */
  GPIO_InitStructure.GPIO_OType = GPIO_OType_PP;
  GPIO_InitStructure.GPIO_PuPd = GPIO_PuPd_UP;
  GPIO_InitStructure.GPIO_Mode = GPIO_Mode_AF;
  GPIO_InitStructure.GPIO_Speed = GPIO_Speed_100MHz;
  GPIO_InitStructure.GPIO_Pin = GPIO_Pin_2;
  GPIO_Init(GPIOA, &GPIO_InitStructure);

  /* Configure PA3 for USART2 RX as AF */
  GPIO_InitStructure.GPIO_Mode = GPIO_Mode_AF;
  GPIO_InitStructure.GPIO_Pin = GPIO_Pin_3;
  GPIO_Init(GPIOA, &GPIO_InitStructure);

  /* Connect PA2 and PA3 to AF */
  GPIO_PinAFConfig(GPIOA, GPIO_PinSource2, GPIO_AF_USART2);		/* TX */
  GPIO_PinAFConfig(GPIOA, GPIO_PinSource3, GPIO_AF_USART2);		/* RX */

  /* DCMI GPIO Configurations ---------------------------------------------------------*/
  /* Configure PC6, PC7, PC8, PC9, PC11 for DCMI Data (D0, D1, D2, D3, D4) as AF */
  GPIO_InitStructure.GPIO_OType = GPIO_OType_PP;
  GPIO_InitStructure.GPIO_PuPd = GPIO_PuPd_UP;
  GPIO_InitStructure.GPIO_Mode = GPIO_Mode_AF;
  GPIO_InitStructure.GPIO_Speed = GPIO_Speed_100MHz;
  GPIO_InitStructure.GPIO_Pin = GPIO_Pin_6 | GPIO_Pin_7 | GPIO_Pin_8 | GPIO_Pin_9 | GPIO_Pin_11;
  GPIO_Init(GPIOC, &GPIO_InitStructure);

  /* Configure PB6, PB8, PB9 for DCMI Data (D5, D6, D7) and PB7 for DCMI VSYNC as AF */
  GPIO_InitStructure.GPIO_OType = GPIO_OType_PP;
  GPIO_InitStructure.GPIO_PuPd = GPIO_PuPd_UP;
  GPIO_InitStructure.GPIO_Mode = GPIO_Mode_AF;
  GPIO_InitStructure.GPIO_Speed = GPIO_Speed_100MHz;
  GPIO_InitStructure.GPIO_Pin = GPIO_Pin_6 | GPIO_Pin_7 | GPIO_Pin_8 | GPIO_Pin_9;
  GPIO_Init(GPIOB, &GPIO_InitStructure);

  /* Configure PA4 and PA6  for DCMI HSYNC and PIXCLK */
  GPIO_InitStructure.GPIO_OType = GPIO_OType_PP;
  GPIO_InitStructure.GPIO_PuPd = GPIO_PuPd_UP;
  GPIO_InitStructure.GPIO_Mode = GPIO_Mode_AF;
  GPIO_InitStructure.GPIO_Speed = GPIO_Speed_100MHz;
  GPIO_InitStructure.GPIO_Pin = GPIO_Pin_4 | GPIO_Pin_6;
  GPIO_Init(GPIOA, &GPIO_InitStructure);

  /* Connect DCMI pins to AF */
  GPIO_PinAFConfig(GPIOC, GPIO_PinSource6, GPIO_AF_DCMI);
  GPIO_PinAFConfig(GPIOC, GPIO_PinSource7, GPIO_AF_DCMI);
  GPIO_PinAFConfig(GPIOC, GPIO_PinSource8, GPIO_AF_DCMI);
  GPIO_PinAFConfig(GPIOC, GPIO_PinSource9, GPIO_AF_DCMI);
  GPIO_PinAFConfig(GPIOC, GPIO_PinSource11, GPIO_AF_DCMI);

  GPIO_PinAFConfig(GPIOB, GPIO_PinSource6, GPIO_AF_DCMI);
  GPIO_PinAFConfig(GPIOB, GPIO_PinSource7, GPIO_AF_DCMI);
  GPIO_PinAFConfig(GPIOB, GPIO_PinSource8, GPIO_AF_DCMI);
  GPIO_PinAFConfig(GPIOB, GPIO_PinSource9, GPIO_AF_DCMI);

  GPIO_PinAFConfig(GPIOA, GPIO_PinSource4, GPIO_AF_DCMI);
  GPIO_PinAFConfig(GPIOA, GPIO_PinSource6, GPIO_AF_DCMI);

  /* Common GPIO Configurations ---------------------------------------------------------*/
  /* Configure PA0 as Input for TRIGGER-Pushbutton */
  GPIO_InitStructure.GPIO_PuPd = GPIO_PuPd_NOPULL;
  GPIO_InitStructure.GPIO_Mode = GPIO_Mode_IN;
  GPIO_InitStructure.GPIO_Pin = GPIO_Pin_0;
  GPIO_Init(GPIOA, &GPIO_InitStructure);

  /* Configure PA5 as Output for TRIGGER-Signal */
  GPIO_InitStructure.GPIO_OType = GPIO_OType_PP;
  GPIO_InitStructure.GPIO_PuPd = GPIO_PuPd_NOPULL;
  GPIO_InitStructure.GPIO_Mode = GPIO_Mode_OUT;
  GPIO_InitStructure.GPIO_Speed = GPIO_Speed_100MHz;
  GPIO_InitStructure.GPIO_Pin = GPIO_Pin_5;
  GPIO_Init(GPIOA, &GPIO_InitStructure);

  /* Configure PA7 as Input for READY */
  GPIO_InitStructure.GPIO_PuPd = GPIO_PuPd_NOPULL;
  GPIO_InitStructure.GPIO_Mode = GPIO_Mode_IN;
  GPIO_InitStructure.GPIO_Pin = GPIO_Pin_7;
  GPIO_Init(GPIOA, &GPIO_InitStructure);

  /* Configure PD12, PD13, PD14 and PD15 as Output for LEDs (green, orange red blue) */
  GPIO_InitStructure.GPIO_OType = GPIO_OType_PP;
  GPIO_InitStructure.GPIO_PuPd = GPIO_PuPd_NOPULL;
  GPIO_InitStructure.GPIO_Mode = GPIO_Mode_OUT;
  GPIO_InitStructure.GPIO_Speed = GPIO_Speed_100MHz;
  GPIO_InitStructure.GPIO_Pin = GPIO_Pin_12 | GPIO_Pin_13 | GPIO_Pin_14 | GPIO_Pin_15;
  GPIO_Init(GPIOD, &GPIO_InitStructure);


}/* GPIO_Config */


/* USART Configurations ---------------------------------------------------------*/
void USART_Config(void)
{
  USART_InitTypeDef USART_InitStruct;
  /* USARTx configured as follow:
          - BaudRate = 115200 baud
          - Word Length = 8 Bits
          - One Stop Bit
          - No parity
          - Hardware flow control disabled (RTS and CTS signals)
          - Receive and transmit enabled
    */
  /* Configure USART2 */
  USART_InitStruct.USART_BaudRate = 115200;
  USART_InitStruct.USART_WordLength = USART_WordLength_8b;
  USART_InitStruct.USART_StopBits = USART_StopBits_1;
  USART_InitStruct.USART_Parity = USART_Parity_No;
  USART_InitStruct.USART_HardwareFlowControl = USART_HardwareFlowControl_None;
  USART_InitStruct.USART_Mode = USART_Mode_Rx | USART_Mode_Tx;
  USART_Init(USART2, &USART_InitStruct);

  /* Activate USART2 */
  USART_Cmd(USART2, ENABLE);
}/* USART_Config */


/* Delay function  ...TBD ---------------------------------------------------------*/
void Delay(__IO uint32_t nCount)
{
  while(nCount--)
  {
  }
}/* Delay */
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
